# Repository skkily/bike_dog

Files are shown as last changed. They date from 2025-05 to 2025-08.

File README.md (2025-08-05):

# 爱车看门狗

基于ML307R与RP2040(树莓派Pico)实现的自行车挪动预警与定位硬件
核心功能是在检测到震动时, 向用户手机推送一条通知, 起到提醒作用.

## 软硬件展示



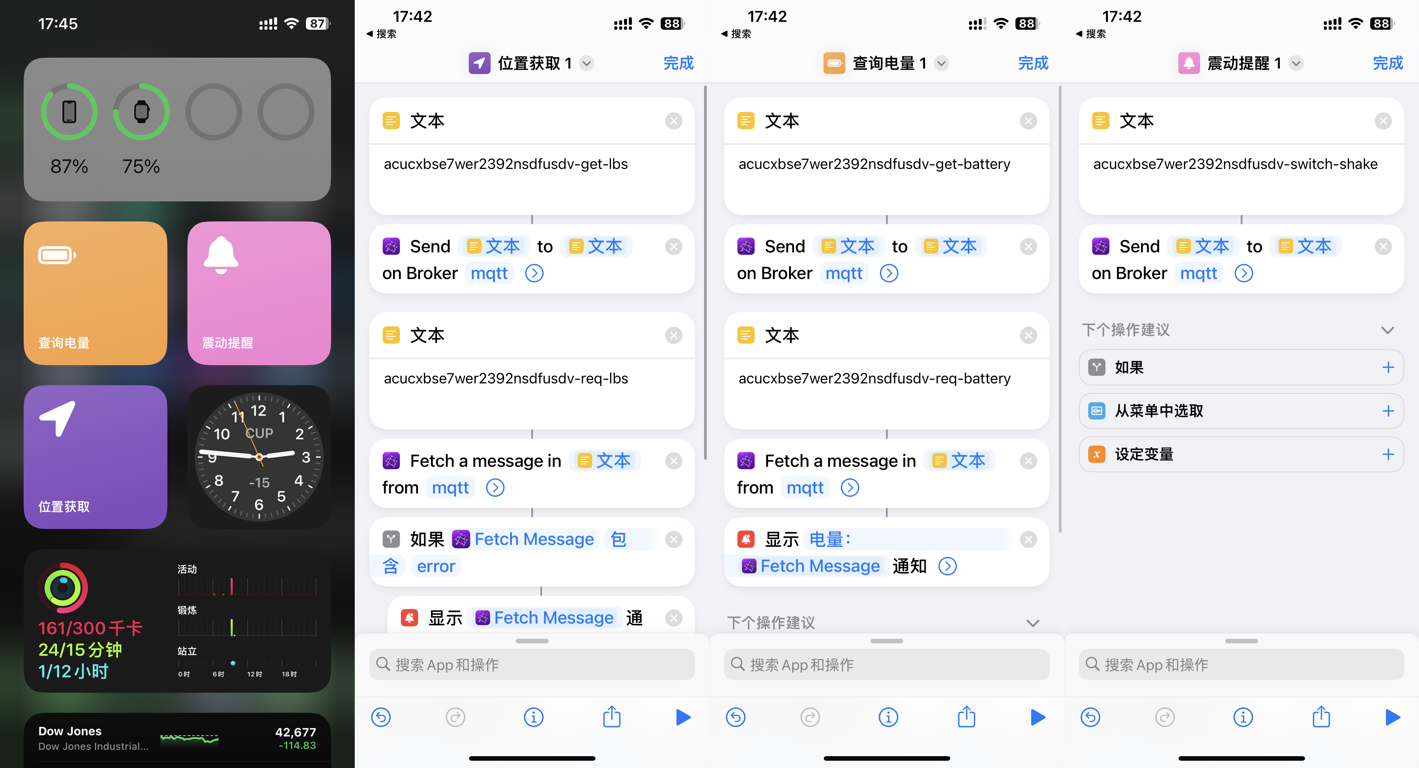
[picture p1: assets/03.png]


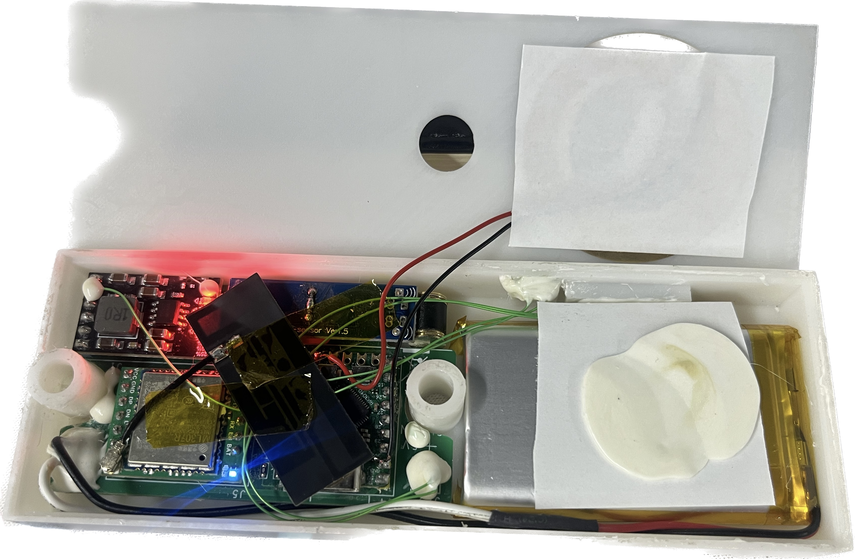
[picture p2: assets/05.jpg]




## 计划添加的功能

* MQTT: 离线提醒

## 功能配置

### 准备工作-设置HTTP与MQTT

#### HTTP 通知

* IOS 使用 Bark 可以获得一个 HTTP 通知链接, 把它放在 main.py 的 NOTIFY_URL 中即可
* 想要全平台兼容的话, 可以使用 Server酱 来实现通知, 自行谷歌教程

#### MQTT 设置[可选]

这个功能为**可选功能**, 不影响核心的震动提醒功能的运作, 且启用后**耗电增加**

MQTT是为了可以与设备进行交互, 目前可以实现:

* 获取设备电量
* 开启/关闭震动提醒
* 获取当前位置

服务端部分设置: 

* 如果不在意安全, 代码默认已经配置了 MQTT 公共服务器, 你只需要改一下 UNIID 即可
  * 在意安全可以自己搭建 MQTT 服务器 本教程不提供.
* 定位部分的设置, 要注册高德开发者账号, 然后申请 WEB API, 获得 key 后, 填写到 LBS_API 即可

客户端部分设置: 

* 本教程提供 IOS 版本的 MQTT 客户端方案
* 其他的方案有 MQTT 网页客户端/其他APP 本教程不提供.

### 为硬件安装固件

1. 在vscode中安装 Raspberry Pi Pico 扩展与 IntelliCode 扩展

2. 给 Pico 烧录好 MicroPython 的 uf2 固件 (自行谷歌)

3. 打开main.py, 对其进行配置

```python
NOTIFY_URL = '' # 填入推送通知的链接(注意最后带 / ), 如 Bark 的 http://api.day.app/TX72mvgBTSoGqy5F/
JUST_NOTIFY = False # 如果为 True 则仅使用通知不使用 MQTT, 会缺少 电量查询/定位/关闭通知 等功能, 但同时节约电量
# 如果只需要通知功能, 或者为了省电, 只需要填写 NOTIFY_URL
# 并且 JUST_NOTIFY = True
# 此时下面的项目不需要填写

MQTT_URL = 'broker.emqx.io' # 公共的 MQTT 服务器, [唯一ID] 一定要自己重设, 或者为了安全可以换用自己的服务器
MQTT_PORT = 1883 # 端口
MQTT_USERNAME = '' # 用户名 (公共服务器不需要填)
MQTT_PASSWORD = '' # 密码 (功能服务器不需要填)

UNIID = 'acucxbse7wer2392nsdfusdv' # 唯一ID, 随便敲一些字符就行, 主要是公共服务器会订阅有冲突问题
LBS_API = '' # 高德开静态地图定位API, 用自己的API
```

4. 点击 Run 验证功能是否正常
5. 点击 All commands -> Upload Project To Pico
6. 关闭 VsCode, 设备重新上一次电, 验证功能是否正常

### 如何验证功能是否正常?

1. 设备开机会发送通知(爱车看门狗 震动检测开启), 未发送则表示有问题
2. 摇动设备会发送通知
3. 验证 MQTT 功能是否正常
   1. IOS设备使用下面章节的功能按钮来测试即可
   2. 其他平台验证 本教程不提供

## [IOS平台] 查看/设置 设备

### 快捷指令的设置

点击分享的链接获得快捷指令模版, 在 [填写你自己的UNIID] 中填写好, 验证是否有效.

改好UNIID后如图, 可以添加桌面或者负一屏 (UNIID示例取自 main.py 中的默认值):



### 快捷指令🔗分享

震动提醒: https://www.icloud.com/shortcuts/cb29e71f1fa84ab0826500942d10e883

查询电量: https://www.icloud.com/shortcuts/9b71ff0aa79f40c9a60abf1565f751ab

位置获取: https://www.icloud.com/shortcuts/a12aa330ff734be7917f60d623da9966

## 定位演示

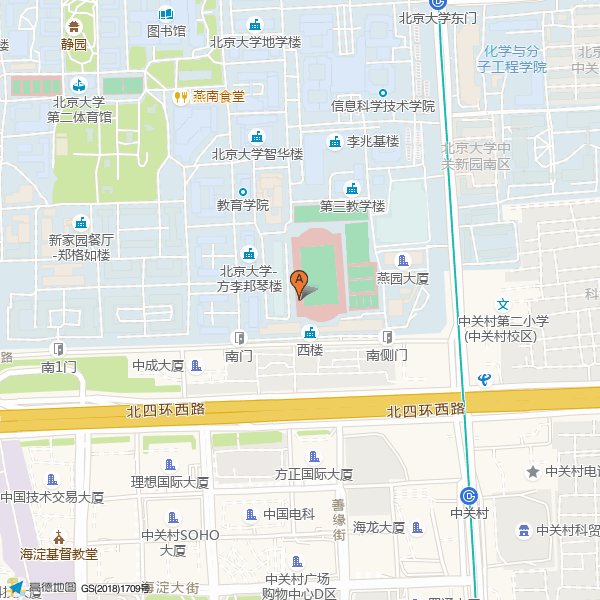
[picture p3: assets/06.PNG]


## 硬件相关说明

### 物料表

* 单片机: 树莓派 pico mini rp2040
* 4G模块: 中移ML307R-DL
  * 最好选带流量的那种
* 震动传感器: 801S 3脚 震动开关
* 电池: 规格903759  2500毫安时
* 充放电模块: 2A 5V充放电一体模块3.7V/4.2V锂电池充电升压移动电源板充放保护
  * 最好选一个没有最低电流限制的, 长出5V的, 防止电流过小自动断电

### PCB原理图:

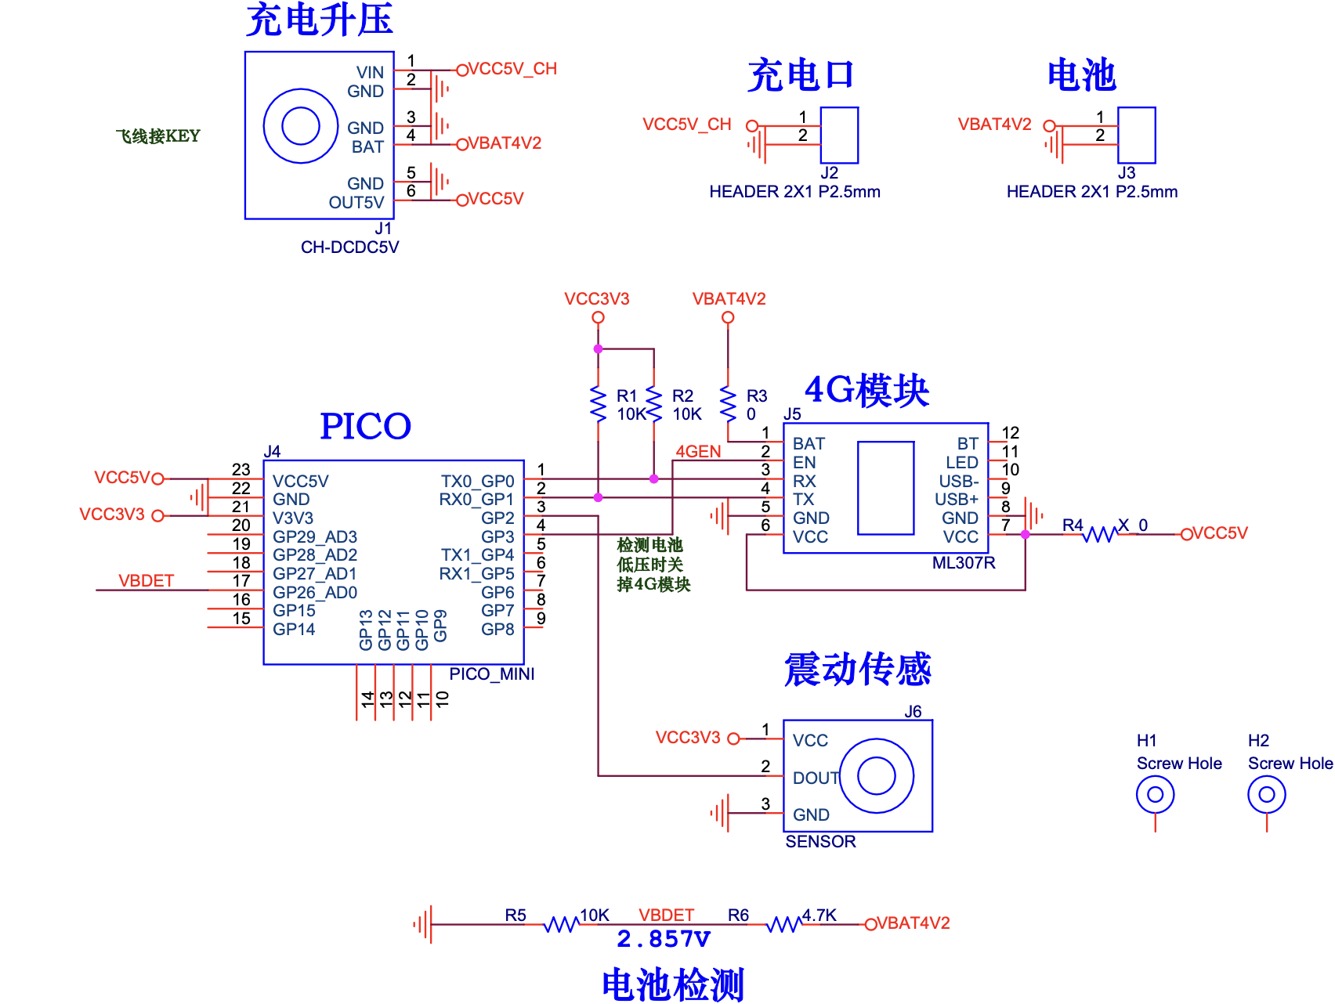
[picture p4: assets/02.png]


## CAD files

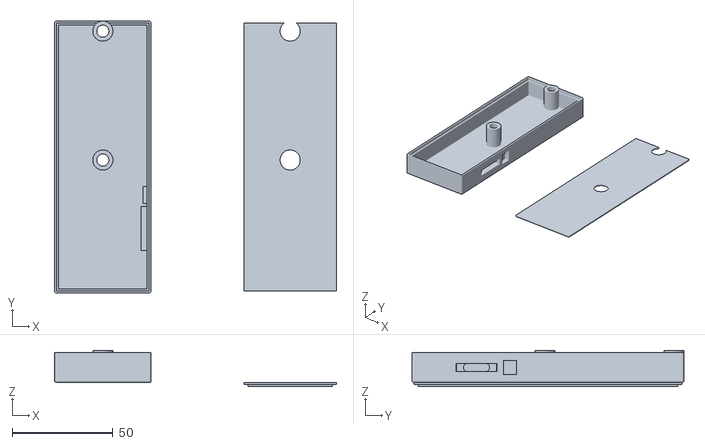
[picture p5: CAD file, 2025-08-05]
STL/bike_dog.stl
140.0 x 135.0 x 18.0

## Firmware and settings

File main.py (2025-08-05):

from machine import UART, Pin, Timer, ADC, PWM
import time
import uerrno

NOTIFY_URL = '' # 填入推送通知的链接(注意最后带 / ), 如 Bark 的 http://api.day.app/TX72mvgBTSoGqy5F/
JUST_NOTIFY = False # 如果为 True 则仅使用通知不使用 MQTT, 会缺少 电量查询/定位/关闭通知 等功能, 但同时节约电量
# 如果只需要通知功能, 或者为了省电, 只需要填写 NOTIFY_URL
# 并且 JUST_NOTIFY = True
# 此时下面的项目不需要填写

MQTT_URL = 'broker.emqx.io' # 公共的 MQTT 服务器, [唯一ID] 一定要自己重设, 或者为了安全可以换用自己的服务器
MQTT_PORT = 1883 # 端口
MQTT_USERNAME = '' # 用户名 (公共服务器不需要填)
MQTT_PASSWORD = '' # 密码 (功能服务器不需要填)

UNIID = 'acucxbse7wer2392nsdfusdv' # 唯一ID, 随便敲一些字符就行, 主要是公共服务器会订阅有冲突问题
LBS_API = '' # 高德静态地图定位API, 用自己申请的API

# 系统配置部分
SHAKE_CHECK_TIME = 5000 # 震动检测时间
BEEP_PIN = 9 # 蜂鸣器引脚
# 以下为代码部分, 到此配置完全结束

def read_ini(filename):
    config = {}
    current_section = None

    try:
        with open(filename, 'r') as f:
            for line in f:
                line = line.strip()
                if not line or line.startswith(';') or line.startswith('#'):
                    continue
                if line.startswith('[') and line.endswith(']'):
                    current_section = line[1:-1]
                    config[current_section] = {}
                elif '=' in line and current_section:
                    key, value = line.split('=', 1)
                    config[current_section][key.strip()] = value.strip()
        return config

    except OSError as e:
        if e.args[0] == uerrno.ENOENT:
            return None
        else:
            raise

config = read_ini('config.ini')
if config is not None:
    ret = config['main_config']['lbs_api']
    if len(ret) > 0:
        LBS_API = ret
    ret = config['main_config']['uniid']
    if len(ret) > 0:
        UNIID = ret
    ret = config['main_config']['notify_url']
    if len(ret) > 0:
        NOTIFY_URL = ret


class ML307R_MQTT_HTTP(object):
    def __init__(self,rx,tx,u_num=0):
        self.uart=UART(u_num,115200,rx=Pin(rx),tx=Pin(tx),rxbuf=2048,txbuf=2048)
        self.rx_reading = False
        time.sleep(1)
        self.timer = Timer(-1)
        self.cb_funcs = {}
        self.header=[]
        self.network_ready()

    def start_rx_server(self):
        self.rx_reading = True
        self.timer.init(period=2000, mode=Timer.PERIODIC, callback=self.rx_server)

    def stop_rx_server(self):
        self.timer.deinit()
        self.rx_reading = False

    def rx_server(self, data) -> None:
        ret = self.uart.read()
        if ret is not None:
            print('[INFO] ' + ret.decode())

        ret = self.at_command('MQTTREAD','0')
        if ret is not None:
            parts = ret.split(b',')
            msg_count = int(parts[1].decode())
            while msg_count > 0:
                ret = self.at_command('MQTTREAD','0,1')
                if ret is None:
                    return
                msgs = ret.split(b',')
                topic = msgs[2][1:-1].decode()
                if topic in self.cb_funcs:
                    self.cb_funcs[topic](msgs[4])

                msg_count = msg_count - 1

    def at_sender(self, dat, t = 1) -> (bytes | None):
        rx_server_status = self.rx_reading
        if rx_server_status:
            self.stop_rx_server()
        
        if dat:
            self.uart.write('AT+' + dat + '\r\n')
            # print('AT+' + dat + '\r\n')
        
        ret = None
        if t != 0:
            time.sleep(0.1 * t)
            ret = self.uart.read()

        if rx_server_status:
            self.start_rx_server()
        return ret
    
    def at_command(self, cmd, var = '', t = 1) -> (bytes | None):
        ret = self.at_sender(cmd + '=' + var, t)
        if ret is None:
            return None
        if ret.find(cmd.encode()) != -1:
            val = ret[ret.find(cmd.encode()) + len(cmd.encode()) + 2:]
            val = val[:val.find(b'\r\n')]
            return val

    def at_wait_command(self, key):
        rx_server_status = self.rx_reading
        if rx_server_status:
            self.stop_rx_server()

        while True:
            ret = self.uart.read()
            val = None
            if ret is not None:
                if ret.find(key.encode()) != -1:
                    val = ret[ret.find(key.encode()) + len(key.encode()) + 2:]
                    val = val[:val.find(b'\r\n')]
                    break
            time.sleep(0.1)

        if rx_server_status:
            self.start_rx_server()
        return val
    
    def mqtt_waitURC(self):
        return self.at_wait_command('MQTTURC')
    
    def network_ready(self):
        print("[INFO] wait network")
        while True:
            ret = self.at_sender('CEREG?')
            if ret is not None:
                # print(ret)
                if b'CEREG: 0,1' in ret:
                    print("[INFO] network ready")
                    return
            time.sleep(0.5)

    def mqtt_link(self):
        print("[INFO] mqtt link")
        ret = self.at_command('MQTTSTATE','0')
        if ret is None:
            return

        if int(ret.decode()) == 2:
            self.at_command('MQTTDISC','0')

        self.at_command('MQTTCFG', '"cached",0,1')

        login_msg = ''
        if len(MQTT_USERNAME) > 0:
            login_msg = ',' + MQTT_USERNAME + ',' + MQTT_PASSWORD
        self.at_command('MQTTCONN','0,"' + MQTT_URL +'",' + str(MQTT_PORT) +',"' + UNIID +'"' + login_msg, 0)
        print("[URC]" , self.mqtt_waitURC())

        self.start_rx_server()

        # self.at_command('MLPMCFG','"sleepmode",2,0')
        # self.at_command('MLPMCFG','"delaysleep",2')
        time.sleep(0.5)

    def mqtt_sub(self, topic, cb):
        print("[INFO] submit topic: " + topic)
        self.at_command('MQTTSUB','0,"' + topic + '",0', 0)
        print("[URC]" , self.mqtt_waitURC())
        self.cb_funcs[topic] = cb
    
    def mqtt_publish(self, topic, qos, text):
        msg = '0,' + topic + ',' + str(qos) + ',0,0,' + str(len(text)) + ',"' + text + '"'
        # print('[SEND MSG] ', msg)
        self.at_command('MQTTPUB', msg)

    def get_response(self,info):
        nx=info.split(b'MHTTPURC: "content"')
        rep_1=nx[1].split(b",")
        rep=b"".join(rep_1[5:])
        return rep
    
    def get_url(self,url_1,url_2,t=15):
        self.at_sender('MHTTPCREATE="'+url_1+'"')
        info=self.at_sender('MHTTPREQUEST=0,1,0,"'+url_2+'"',t)
        self.at_sender('MHTTPHEADER=0')
        return self.get_response(info)
    
    def get_url_ssl(self,url_1,url_2,t=15):
        self.at_sender('MHTTPCREATE="'+url_1+'"')
        self.at_sender('MHTTPCFG="ssl",0,1,1')
        info=self.at_sender('MHTTPREQUEST=0,1,0,"'+url_2+'"',t)
        self.at_sender('MHTTPHEADER=0')
        return self.get_response(info)
    
    def make_url(self,url):
        url_1="/".join(url.split("/")[0:3])
        url_2="/"+"/".join(url.split("/")[3:])
        return [url_1,url_2]
    
    def get(self,url):
        ua=self.make_url(url)

        if "https" in ua[0]:
            ba=self.get_url_ssl(ua[0],ua[1])
        else:
            ba=self.get_url(ua[0],ua[1])
        return ba

class Bike_Dog(object):
    def __init__(self):
        self.network_module = ML307R_MQTT_HTTP(1,0)
        self.trig = Pin('GP2', Pin.IN)
        self.trig_stat = False
        self.beep_auto = False
        self.last_call_time = time.ticks_ms()  # 初始化时间

        if not JUST_NOTIFY:
            self.network_module.mqtt_link()
            self.network_module.mqtt_publish(UNIID +'-online', 0, 'online')

            self.network_module.mqtt_sub(UNIID +'-switch-shake', self.cb_shake_change)
            self.network_module.mqtt_sub(UNIID +'-get-lbs', self.cb_LBS)

            self.battery = ADC(26)
            self.network_module.mqtt_sub(UNIID +'-get-battery', self.cb_BT)
            self.network_module.mqtt_sub(UNIID +'-beep', self.cb_beep)
            self.network_module.mqtt_sub(UNIID +'-switch-autobeep', self.cb_autobeep)

        self.shake_monitor_start() # 开启震动检测, 同时表示初始化完毕
        self.check_bettery() # 检测电池电量

    def cb_shake_change(self, *args):
        if self.trig_stat:
            self.shake_monitor_stop()
        else:
            self.shake_monitor_start()
    
    def check_bettery(self):
        bt_per = (self.battery.read_u16() / 65535.0) * 100
        if bt_per < 74:
            self.network_module.get(NOTIFY_URL + "爱车看门狗/电池电量低")
        return bt_per

    def cb_BT(self, *args):
        self.network_module.mqtt_publish(UNIID +'-req-battery', 0, str(self.check_bettery()))

    def cb_LBS(self, *args):
        # print('[INFO] get LBS')
        self.network_module.at_command('MLBSCFG', '"method",40')
        self.network_module.at_command('MLBSCFG', '"nearbtsen",1')
        self.network_module.at_command(cmd = 'MLBSLOC', t=0)
        locate = self.network_module.at_wait_command('MLBSLOC')
        print("[INFO] LBS return: ", locate)
        if int(locate[:3].decode()) == 100:
            gps = locate[4:].decode()
            map_url = 'https://restapi.amap.com/v3/staticmap?location=' \
                + gps + '&zoom=15&size=600*600&markers=mid,,A:' + gps + \
                '&key=' + LBS_API
            self.network_module.mqtt_publish(UNIID +'-req-lbs', 0, map_url)
        else:
            self.network_module.mqtt_publish(UNIID +'-req-lbs', 0, "lbs get error, pls retry -> " + locate.decode())

    def cb_beep(self, *args):
        self.beep(0.2, 3)

    def cb_autobeep(self, *args):
        self.beep_auto = not self.beep_auto
        if self.beep_auto:
            self.beep()
            self.network_module.get(NOTIFY_URL + "爱车看门狗/主动蜂鸣打开")
        else:
            self.beep()
            self.network_module.get(NOTIFY_URL + "爱车看门狗/主动蜂鸣关闭")

    def shake_monitor_start(self):
        self.beep()
        self.trig.irq(trigger=Pin.IRQ_RISING, handler=self.trig_callback)
        self.trig_stat = True
        self.network_module.get(NOTIFY_URL + "爱车看门狗/震动检测开启")

    def shake_monitor_stop(self):
        self.beep()
        self.trig.irq(None)
        self.trig_stat = False
        self.network_module.get(NOTIFY_URL + "爱车看门狗/震动检测关闭")

    def beep(self, interval_time = 0.1, count = 1):
        beeper = PWM(Pin(BEEP_PIN))
        beeper.freq(3600)
        beeper.duty_u16(32767)
        while count > 0:
            beeper.freq(3500)
            time.sleep(interval_time)
            beeper.freq(3600)
            time.sleep(interval_time)
            count = count - 1
        beeper.deinit()

    def trig_callback(self, trig: Pin):
        self.trig.irq(None) # 关中断, 限制中断进入的频率
        # print(time.ticks_ms())
        current_time = time.ticks_ms()
        diff = time.ticks_diff(current_time, self.last_call_time)
        
        if diff > SHAKE_CHECK_TIME:
            print("[INFO] detect shake")
            self.network_module.get(NOTIFY_URL + "爱车看门狗/检测到震动")
            if self.beep_auto:
                self.beep(0.2, 3)
            # clock = mm.command('AT+CCLK?').decode('utf-8').split('"')[1].split(',')[1].split('+')[0]
            self.last_call_time = current_time

    def run(self):
        if self.trig_stat:
            self.trig.irq(trigger=Pin.IRQ_RISING, handler=self.trig_callback)


print('[INFO] your uniid: ' + UNIID)
print('[INFO] your lbs_api: ' + LBS_API)

bd = Bike_Dog()

while True:
    bd.run()
    time.sleep(3)
    

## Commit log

2025-08-01 支持蜂鸣器功能
2025-08-05 防止过多的中断导致mqtt延迟过高
2025-08-05 stl module
    [bike_dog.stl]
